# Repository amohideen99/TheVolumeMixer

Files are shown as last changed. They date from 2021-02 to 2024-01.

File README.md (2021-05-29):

# The Volume Mixer
physically control the volume of your applications

### Features
- four different knobs settable to any applications
- RGB LED bar indication for volume
- 2.8 Watts/channel integrated Class D Speaker Amp
- data and power over single USB
- runs Arduino as Metro M0 Express

### Default Application Settings
```
 Knob 1 - Main Volume
 Knob 2 - Google Chrome
 Knob 3 - Discord && Spotify
 Knob 4 - CS:GO && Valorant
 ```

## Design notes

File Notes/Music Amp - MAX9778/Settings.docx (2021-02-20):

MAX9778 pin settings

Gain for amps: set to 2 for gain a and then 2.5 for gain b

Aux jack should be 2.2 volts peak to peak max so gain of 1->2 should keep us within 5v range

Gain is Rf/Rin

Follow typical application 2 for bast boosting and cap values keep this

Gain for typical application is 1 for a and over 2 for b keep this

Follow typical applications for most

Set INL2 and INR2 to be grounded through 15k resistor and cap

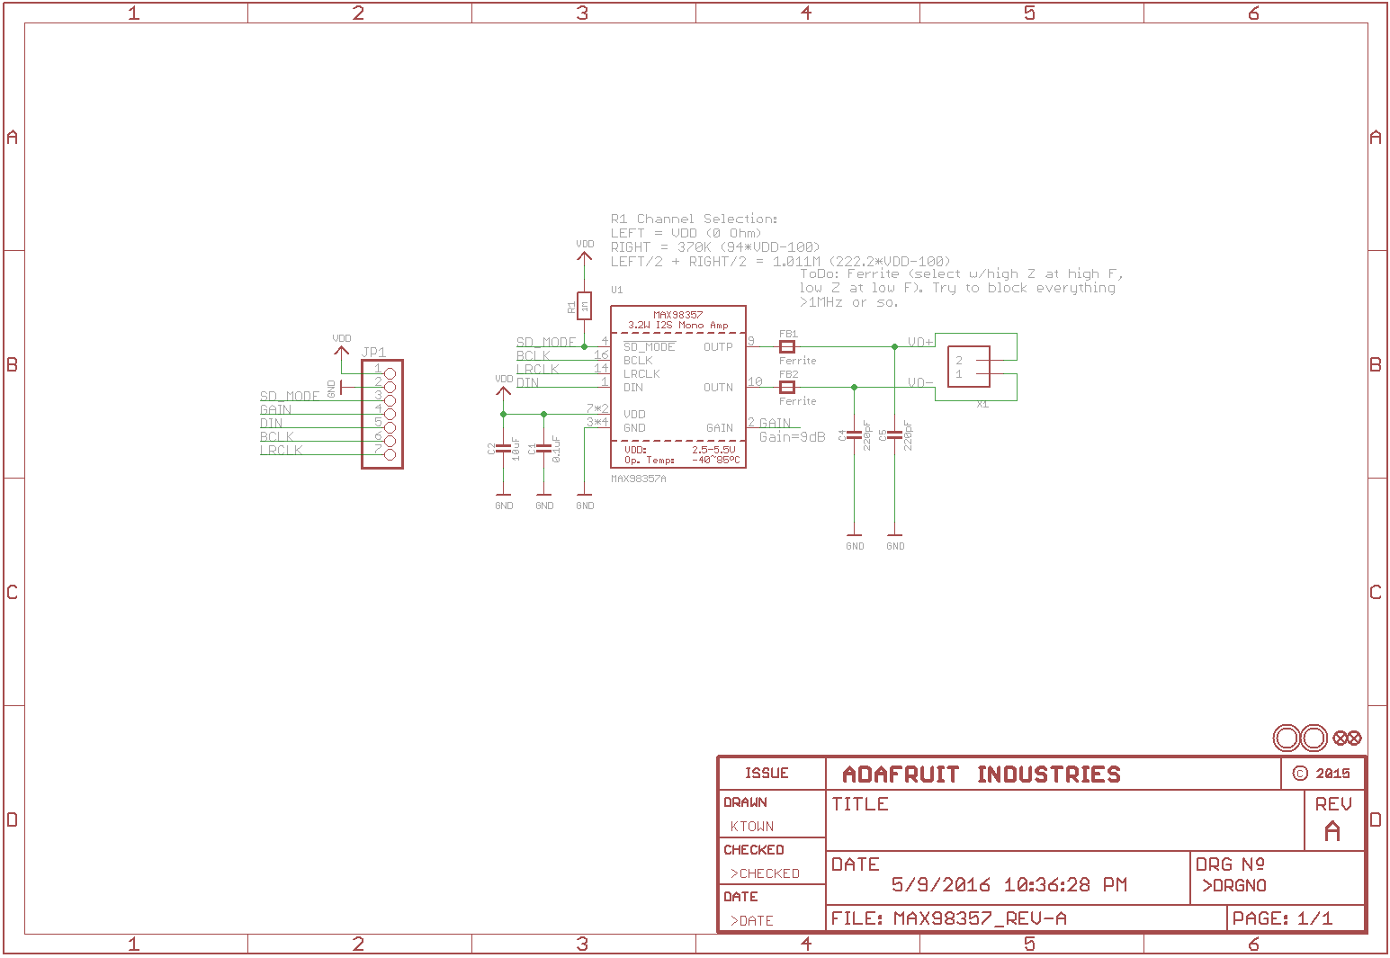
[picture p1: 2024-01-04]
Component Docs/Audio Amp - MAX98357/Adafruit Schematic.png

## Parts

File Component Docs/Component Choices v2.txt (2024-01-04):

MCU

Necessities: 4 ADC at least, I2S, Arduino Compatibility

  - **ESP32**
    | will be flashing as TinyPICO for Arduino (https://www.adafruit.com/product/4335#technical-details)
        needs PICO-D4 MCU

    | will be using online BluetoothA2DPSink for music (https://www.pschatzmann.ch/home/2020/03/27/1255/)
        need GPIOs 26, 25, 22 for I2S
    - 13 ADC
    - 2 I2S Audio
    - No Integrated USB (need UART to USB converter)
    - Bluetooth API for A2DP

  - NRF52832
    - enough GPIO
    - Bluetooth
    - Wifi (could be interesting feature)
    - can't find Bluetooth API

	- SAMD21
    - no Bluetooth features
    - enough ADC's
    - enough GPIOs

Audio Amp

	- *MAX98357*
		- arduino compatible
		- 16/24/32 bit DAC available
		- Single Channel or Mono

	- LM49450
		- 24 bit DAC
		- Stereo
    - 2.5 W per Channel
    - Digital Volume Control
    - I2C Interface

  - SSM2518
    - 2W x 2 Channel (Stereo)
    - I2C Configuration X

  - TLV320DAC32
     - I2C X
     - I2S

Pots
  - PTV09A-4020F-B203
    -

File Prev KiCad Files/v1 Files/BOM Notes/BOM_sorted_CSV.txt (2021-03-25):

0.1uF,C1 C6 C8 C9 C10 C14 C15 C16,1276-6985-1-ND,,8,24
1uF,C2 C3 C7 C11 C12 C13 C17 C20 C21,1276-1943-1-ND,,9,27
9pF,C4 C5,1276-2142-1-ND,,2,6
0.047uF,C18 C19,1276-1063-1-ND,,2,6
LED_RGBA,D1 D2 D3 D4 D5 D6,CLV1A-FKB-CK1VW1DE1BB7C3C3CT-ND,,6,18
LED,D7,754-2165-1-ND,,1,3
Conn_01x01_Male,J1 J2 J4 J5 J6 J7 J9 J10,,,8,24
Conn_01x05,J3,,,1,3
SJ1-3544,J8,CP1-3544-ND,1.01,1,3
MountingHole,MH1 MH2 MH3,,,3,9
10k,R1 R3,541-10KAQCT-ND,,2,6
3.3k,R2,541-CRCW06033K30JNEBCT-ND,,1,3
2.2k,R4,541-2.2KGCT-ND,,1,3
100k,R5,541-CRCW0603100KJNEBCT-ND,,1,3
100.0,R6 R7,541-CRCW0603100RFKEBCT-ND,,2,6
R_POT_US,RV1 RV2 RV3 RV4,PTV09A-4020F-B203-ND,,4,12
SW_Push,SW1,SW415-ND,,1,3
TLC5947RHB,U1,296-48690-1-ND,,1,3
ATSAMD21G18A-A,U2,ATSAMD21G18A-AUTCT-ND,,1,3
AP2127K-3.3,U3,AP2127K-3.3TRG1DICT-ND,,1,3
TPA2017,U4,296-24395-1-ND,,1,3
32.768kHz,Y1,2195-CM8V-T1A-32.768KHZ-9PF-20PPM-TA-QCCT-ND,,1,3

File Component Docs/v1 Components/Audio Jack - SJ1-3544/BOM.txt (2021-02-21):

3DX_CUI_DEVICES_Supplier: CUI Devices
3DX_CUI_DEVICES_Description: 3.5 mm Right-Angle Stereo Jack, 4 Pin PCB Mount, Threaded w/ Nut
3DX_CUI_DEVICES_Model Number: SJ1-3544

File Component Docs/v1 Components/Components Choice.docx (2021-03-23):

Audio Amp Possibilities

SSM4567 – Analog Devices

https://www.analog.com/en/products/ssm4567.html

- I2S

MAX98357A – MAXIM Integrated

https://www.maximintegrated.com/en/products/analog/audio/MAX98357A.html

- I2S
- Mono

SSM2315 – Analog Devices

https://www.analog.com/en/products/ssm2315.html#product-overview

- Differential
- 3W
- Mono

MAX9778 – MAXIM Integrated

https://datasheets.maximintegrated.com/en/ds/MAX9777-MAX9778.pdf

- Differential In
- I2C configurable
- Headphone/ Speaker automatic detection and switching
- 3W speaker out
- Can switch between 2 inputs
- Don’t need I2C for Max9778

LM49450 - Texas Instruments

https://www.ti.com/product/LM49450

- Headphone detection
- Class D
- Stereo 2.5W per channel
- I2C configurable
- 32 step volume control

TPA2017D2 – TI

- Class D
- 2.8W per channel w/ 4 Ohm Load @ 5V
- WFN Package
- Smart Gain (automatically determined to avoid clipping and for max amplification)
- 2 pins for setting smart gain configuration
- 1 for shutdown

MCU - ATSAMD21G18

- Program as Feather M0

Rotary Encoder

https://www.digikey.com/en/products/detail/bourns-inc/PEC11R-4220K-S0024/6164059

- 3 GPIOS for each rotary encoder (2 for left/right and 1 for push switch)

Potentiometer - PTV09A-4020U-B103

https://www.digikey.com/en/products/detail/bourns-inc/PTV09A-4020F-B203/3781126

- Single analog read input per potentiometer
- Tie between 3.3V and Ground

RGB LED

https://www.digikey.com/en/products/detail/everlight-electronics-co-ltd/EAST1616RGBB2/8510360

- Common Anode

LED Driver - TLC5947

https://www.ti.com/lit/ds/symlink/tlc5947.pdf?ts=1613292426730&ref_url=https%253A%252F%252Fwww.google.com%252F

- Adafruit libraries
- 24-channel so 8 RGB LEDs
- Constant Current sink
- IRef to set Current (2.5k sets to 20 mA)

LDO - AP212K-3.3

https://www.diodes.com/assets/Datasheets/AP2112.pdf

- 3.3V out
- 300 mA max

Power Options

- Amp works off of 5V so no need (power off 5V)
- SAMD21 has to work off of 3.3V
- TLC5940 can work off of 3V to 5V (power off 5V)
- Rotary encoder should work with 3.3V
- 3.3V LDO for MCU

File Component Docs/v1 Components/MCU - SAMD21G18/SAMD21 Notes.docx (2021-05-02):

Using as a Metro M0, so restrictions

- Only get the GPIO’s used on the Metro
- Analog Inputs can be used as Digital I/O on Metro
- Want to keep as much as same for debug purposes
- CAN use internal pull ups & should be available for pull downs
- Can source 7 mA

Design Points

- USB Data+ at PA25 and USB Data- at PA24
- 1 uF Cap at VddCore
- 0.1 uF for VDDIO
- 1 uF and 0.1 uF for VDDANA
- Reset should go to pushbutton w/ 0.1 uF cap and pull-up

Pinouts

A3 is Volume 1

A4 is Volume 2

A10 (Digital 8) will be Volume knob 3

A11 (Digital 9) will be Volume knob 4

Programming Notes

- Had issues with the crystal
- Managed to run crystalless
  - (not sure if necessary) add #define CRYSTALLESS 1 to the bootloader configuration file in uf2 bootloader
  - Rebuild and flash bootloader as necessary
    - Might not be necessary because bootloader should run cyrstalless anyway
  - Add “-DCRYSTALLESS” to the build flags for metro m0 in the boards.txt file, which is at C:\Users\Ahkeel Mohideen\AppData\Local\Arduino15\packages\adafruit\hardware\samd\1.6.6
    - This tells compiler to compile sketch as crystalless otherwise it will hang as it waits for crystal

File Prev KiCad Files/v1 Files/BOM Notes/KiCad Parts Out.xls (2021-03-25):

C1 | 0.1uF | Capacitor_SMD:C_0603_1608Metric_Pad1.05x0.95mm_HandSolder | ~ | 1276-6985-1-ND |  |  | 1
C2 | 1uF | Capacitor_SMD:C_0603_1608Metric_Pad1.05x0.95mm_HandSolder | ~ | 1276-1943-1-ND |  |  | 1
C3 | 1uF | Capacitor_SMD:C_0603_1608Metric_Pad1.05x0.95mm_HandSolder | ~ | 1276-1943-1-ND |  |  | 1
C4 | 9pF | Capacitor_SMD:C_0603_1608Metric_Pad1.05x0.95mm_HandSolder | ~ | 1276-2142-1-ND |  |  | 1
C5 | 9pF | Capacitor_SMD:C_0603_1608Metric_Pad1.05x0.95mm_HandSolder | ~ | 1276-2142-1-ND |  |  | 1
C6 | 0.1uF | Capacitor_SMD:C_0603_1608Metric_Pad1.05x0.95mm_HandSolder | ~ | 1276-6985-1-ND |  |  | 1
C7 | 1uF | Capacitor_SMD:C_0603_1608Metric_Pad1.05x0.95mm_HandSolder | ~ | 1276-1943-1-ND |  |  | 1
C8 | 0.1uF | Capacitor_SMD:C_0603_1608Metric_Pad1.05x0.95mm_HandSolder | ~ | 1276-6985-1-ND |  |  | 1
C9 | 0.1uF | Capacitor_SMD:C_0603_1608Metric_Pad1.05x0.95mm_HandSolder | ~ | 1276-6985-1-ND |  |  | 1
C10 | 0.1uF | Capacitor_SMD:C_0603_1608Metric_Pad1.05x0.95mm_HandSolder | ~ | 1276-6985-1-ND |  |  | 1
C11 | 1uF | Capacitor_SMD:C_0603_1608Metric_Pad1.05x0.95mm_HandSolder | ~ | 1276-1943-1-ND |  |  | 1
C12 | 1uF | Capacitor_SMD:C_0603_1608Metric_Pad1.05x0.95mm_HandSolder | ~ | 1276-1943-1-ND |  |  | 1
C13 | 1uF | Capacitor_SMD:C_0603_1608Metric_Pad1.05x0.95mm_HandSolder | ~ | 1276-1943-1-ND |  |  | 1
C14 | 0.1uF | Capacitor_SMD:C_0603_1608Metric_Pad1.05x0.95mm_HandSolder | ~ | 1276-6985-1-ND |  |  | 1
C15 | 0.1uF | Capacitor_SMD:C_0603_1608Metric_Pad1.05x0.95mm_HandSolder | ~ | 1276-6985-1-ND |  |  | 1
C16 | 0.1uF | Capacitor_SMD:C_0603_1608Metric_Pad1.05x0.95mm_HandSolder | ~ | 1276-6985-1-ND |  |  | 1
C17 | 1uF | Capacitor_SMD:C_0603_1608Metric_Pad1.05x0.95mm_HandSolder | ~ | 1276-1943-1-ND |  |  | 1
C18 | 0.047uF | Capacitor_SMD:C_0603_1608Metric_Pad1.05x0.95mm_HandSolder | ~ | 1276-1063-1-ND |  |  | 1
C19 | 0.047uF | Capacitor_SMD:C_0603_1608Metric_Pad1.05x0.95mm_HandSolder | ~ | 1276-1063-1-ND |  |  | 1
C20 | 1uF | Capacitor_SMD:C_0603_1608Metric_Pad1.05x0.95mm_HandSolder | ~ | 1276-1943-1-ND |  |  | 1
C21 | 1uF | Capacitor_SMD:C_0603_1608Metric_Pad1.05x0.95mm_HandSolder | ~ | 1276-1943-1-ND |  |  | 1
D1 | LED_RGBA | LED_SMD:LED_Cree-PLCC4_3.2x2.8mm_CCW |  | CLV1A-FKB-CK1VW1DE1BB7C3C3CT-ND |  |  | 1
D2 | LED_RGBA | LED_SMD:LED_Cree-PLCC4_3.2x2.8mm_CCW |  | CLV1A-FKB-CK1VW1DE1BB7C3C3CT-ND |  |  | 1
D3 | LED_RGBA | LED_SMD:LED_Cree-PLCC4_3.2x2.8mm_CCW |  | CLV1A-FKB-CK1VW1DE1BB7C3C3CT-ND |  |  | 1
D4 | LED_RGBA | LED_SMD:LED_Cree-PLCC4_3.2x2.8mm_CCW |  | CLV1A-FKB-CK1VW1DE1BB7C3C3CT-ND |  |  | 1
D5 | LED_RGBA | LED_SMD:LED_Cree-PLCC4_3.2x2.8mm_CCW |  | CLV1A-FKB-CK1VW1DE1BB7C3C3CT-ND |  |  | 1
D6 | LED_RGBA | LED_SMD:LED_Cree-PLCC4_3.2x2.8mm_CCW |  | CLV1A-FKB-CK1VW1DE1BB7C3C3CT-ND |  |  | 1
D7 | LED | LED_SMD:LED_0603_1608Metric_Pad1.05x0.95mm_HandSolder | ~ | 754-2165-1-ND |  |  | 1
J1 | Conn_01x01_Male | TestPoint:TestPoint_Pad_4.0x4.0mm | ~ |  |  |  | 1
J2 | Conn_01x01_Male | TestPoint:TestPoint_Pad_4.0x4.0mm | ~ |  |  |  | 1
J3 | Conn_01x05 | Connector_PinHeader_2.54mm:PinHeader_1x05_P2.54mm_Vertical | ~ |  |  |  | 1
J4 | Conn_01x01_Male | TestPoint:TestPoint_Pad_4.0x4.0mm | ~ |  |  |  | 1
J5 | Conn_01x01_Male | TestPoint:TestPoint_Pad_4.0x4.0mm | ~ |  |  |  | 1
J6 | Conn_01x01_Male | TestPoint:TestPoint_Pad_4.0x4.0mm | ~ |  |  |  | 1
J7 | Conn_01x01_Male | TestPoint:TestPoint_Pad_4.0x4.0mm | ~ |  |  |  | 1
J8 | SJ1-3544 | SJ1-3544 - Audio Jack:CUI_SJ1-3544 |  | CP1-3544-ND | 1.01 | Manufacturer recommendation | 1
J9 | Conn_01x01_Male | TestPoint:TestPoint_Pad_4.0x4.0mm | ~ |  |  |  | 1
J10 | Conn_01x01_Male | TestPoint:TestPoint_Pad_4.0x4.0mm | ~ |  |  |  | 1
MH1 | MountingHole | MountingHole:MountingHole_3.2mm_M3_DIN965_Pad | ~ |  |  |  | 1
MH2 | MountingHole | MountingHole:MountingHole_3.2mm_M3_DIN965_Pad | ~ |  |  |  | 1
MH3 | MountingHole | MountingHole:MountingHole_3.2mm_M3_DIN965_Pad | ~ |  |  |  | 1
R1 | 10k | Resistor_SMD:R_0603_1608Metric_Pad1.05x0.95mm_HandSolder | ~ | 541-10KAQCT-ND |  |  | 1
R2 | 3.3k | Resistor_SMD:R_0603_1608Metric_Pad1.05x0.95mm_HandSolder | ~ | 541-CRCW06033K30JNEBCT-ND |  |  | 1
R3 | 10k | Resistor_SMD:R_0603_1608Metric_Pad1.05x0.95mm_HandSolder | ~ | 541-10KAQCT-ND |  |  | 1
R4 | 2.2k | Resistor_SMD:R_0603_1608Metric_Pad1.05x0.95mm_HandSolder | ~ | 541-2.2KGCT-ND |  |  | 1
R5 | 100k | Resistor_SMD:R_0603_1608Metric_Pad1.05x0.95mm_HandSolder | ~ | 541-CRCW0603100KJNEBCT-ND |  |  | 1
R6 | 100 | Resistor_SMD:R_0603_1608Metric_Pad1.05x0.95mm_HandSolder | ~ | 541-CRCW0603100RFKEBCT-ND |  |  | 1
R7 | 100 | Resistor_SMD:R_0603_1608Metric_Pad1.05x0.95mm_HandSolder | ~ | 541-CRCW0603100RFKEBCT-ND |  |  | 1
RV1 | R_POT_US | Potentiometer - PTV09A-4020F-B203:Potentiometer_Bourns_PTV09A-1_Single_Vertical | ~ | PTV09A-4020F-B203-ND |  |  | 1
RV2 | R_POT_US | Potentiometer - PTV09A-4020F-B203:Potentiometer_Bourns_PTV09A-1_Single_Vertical | ~ | PTV09A-4020F-B203-ND |  |  | 1
RV3 | R_POT_US | Potentiometer - PTV09A-4020F-B203:Potentiometer_Bourns_PTV09A-1_Single_Vertical | ~ | PTV09A-4020F-B203-ND |  |  | 1
RV4 | R_POT_US | Potentiometer - PTV09A-4020F-B203:Potentiometer_Bourns_PTV09A-1_Single_Vertical | ~ | PTV09A-4020F-B203-ND |  |  | 1
SW1 | SW_Push | Button_Switch_SMD:SW_SPST_B3S-1000 |  | SW415-ND |  |  | 1
U1 | TLC5947RHB | Package_DFN_QFN:QFN-32-1EP_5x5mm_P0.5mm_EP3.45x3.45mm | http://www.ti.com/lit/ds/symlink/tlc5947.pdf | 296-48690-1-ND |  |  | 1
U2 | ATSAMD21G18A-A | Package_QFP:TQFP-48_7x7mm_P0.5mm | http://ww1.microchip.com/downloads/en/DeviceDoc/SAM_D21_DA1_Family_Data%20Sheet_DS40001882E.pdf | ATSAMD21G18A-AUTCT-ND |  |  | 1
U3 | AP2127K-3.3 | Package_TO_SOT_SMD:SOT-23-5 | https://www.diodes.com/assets/Datasheets/AP2127.pdf | AP2127K-3.3TRG1DICT-ND |  |  | 1
U4 | TPA2017 | footprints:TPA2017D2RTJR |  | 296-24395-1-ND |  |  | 1
Y1 | 32.768kHz | Crystal:Crystal_SMD_MicroCrystal_CC8V-T1A-2Pin_2.0x1.2mm_HandSoldering | ~ | 2195-CM8V-T1A-32.768KHZ-9PF-20PPM-TA-QCCT-ND |  |  | 1

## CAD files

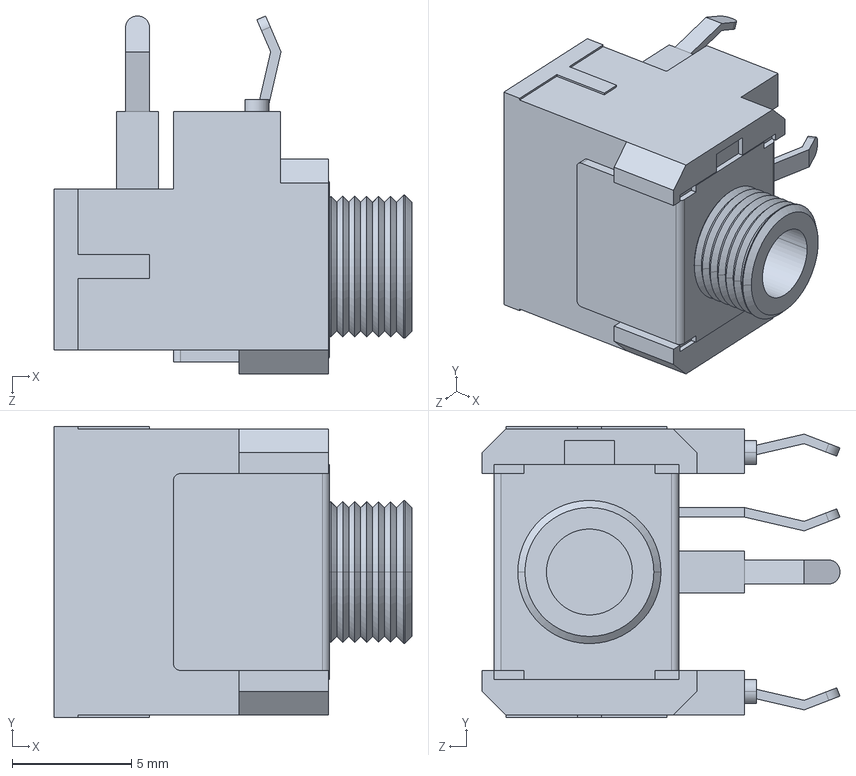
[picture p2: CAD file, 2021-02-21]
Component Docs/v1 Components/Audio Jack - SJ1-3544/CUI_DEVICES_SJ1-3544.step
15.0 x 12.2 x 15.0 mm

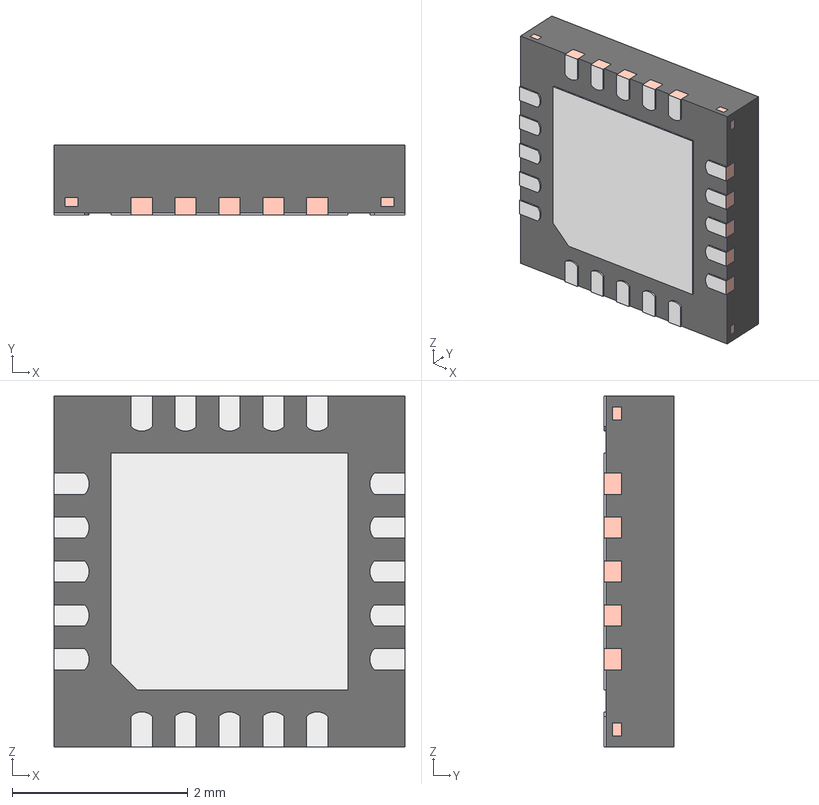
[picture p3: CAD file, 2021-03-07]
Component Docs/v1 Components/Class D Amp - TPA2017D2/STEP/RTJ0020D.stp
4.00 x 0.8 x 4.00 mm
FRAME
PIN1_AREA

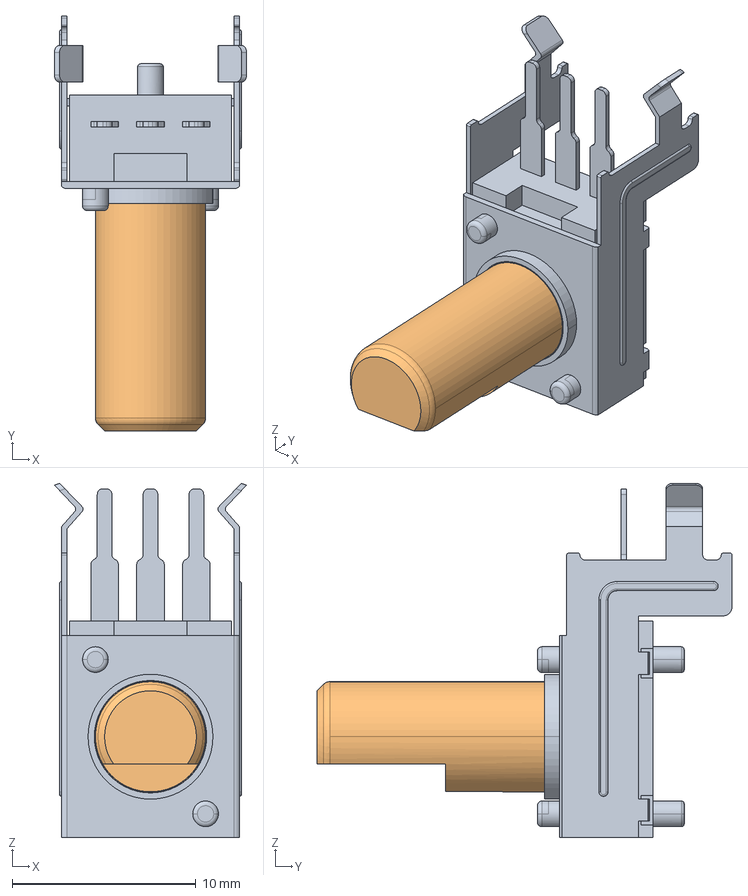
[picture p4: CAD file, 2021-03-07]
Component Docs/v1 Components/Potentiometer - PTV09A-4020F-B203/ptv09a-2x20f-xxxx.stp
10.5 x 22.6 x 19.3 mm

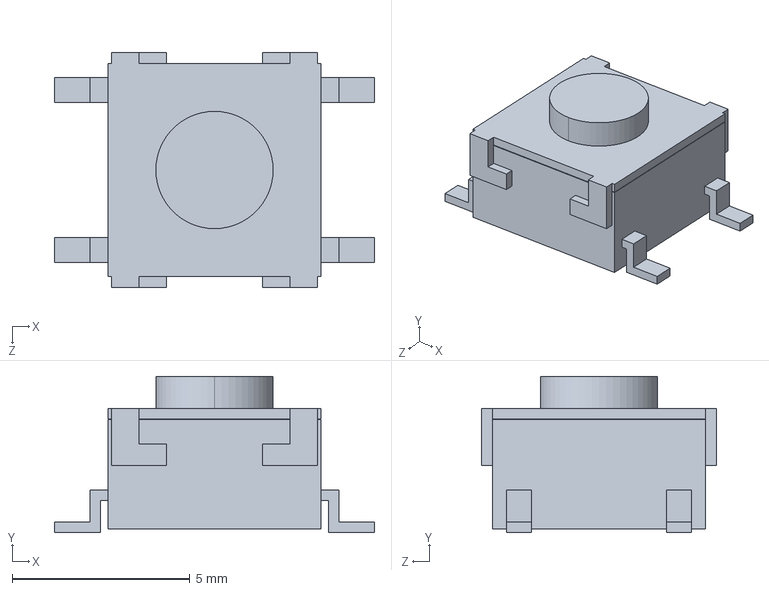
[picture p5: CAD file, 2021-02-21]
Component Docs/v1 Components/Push Button - B3S-1000/B3S_100[].step
9.00 x 4.40 x 6.60 mm

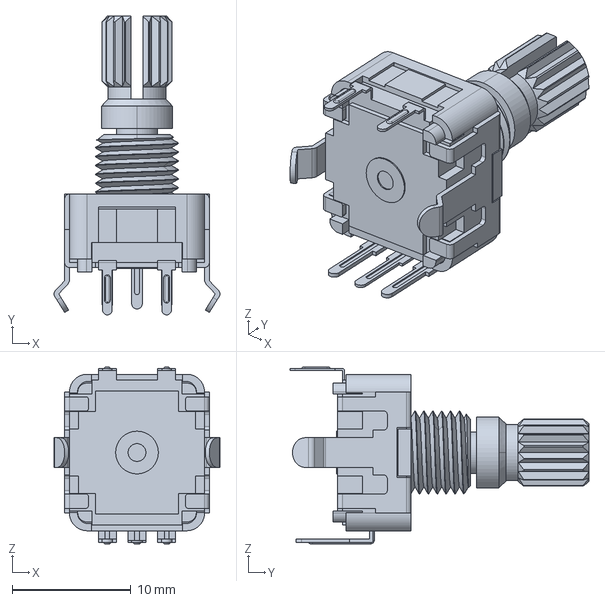
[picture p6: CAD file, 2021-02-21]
Notes/(NO USE) Rotary Encoder - PEC11R-4215K-S0012/pec11r-4x15k-sxxxx.stp
14.0 x 25.2 x 14.9 mm

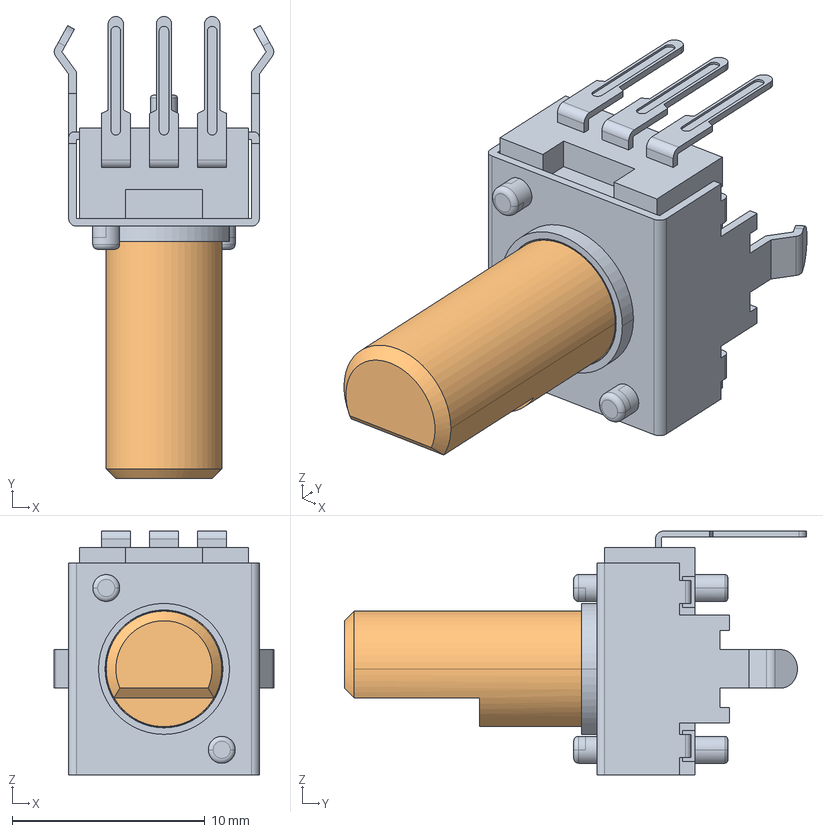
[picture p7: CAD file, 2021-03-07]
Component Docs/v1 Components/Potentiometer - PTV09A-4020F-B203/ptv09a-4x20f-xxxx.stp
11.4 x 24.0 x 12.7 mm

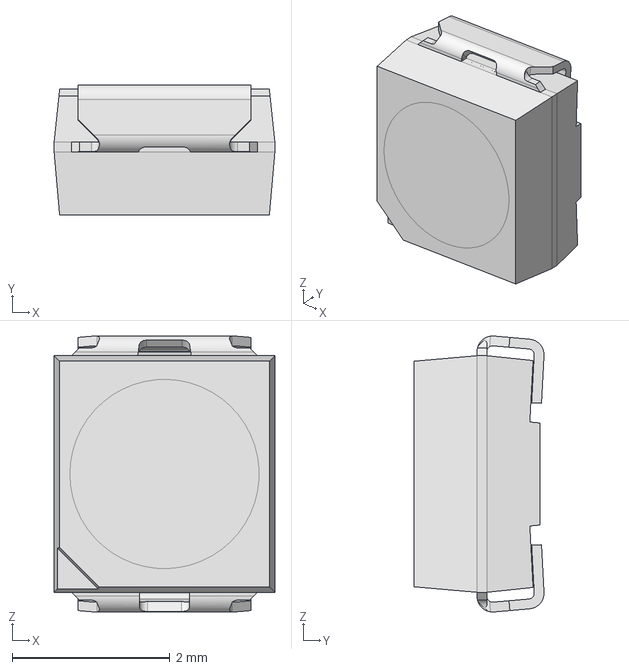
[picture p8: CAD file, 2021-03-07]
Component Docs/v1 Components/82548PLCC-2_package_3D.stp
2.80 x 1.65 x 3.50 mm

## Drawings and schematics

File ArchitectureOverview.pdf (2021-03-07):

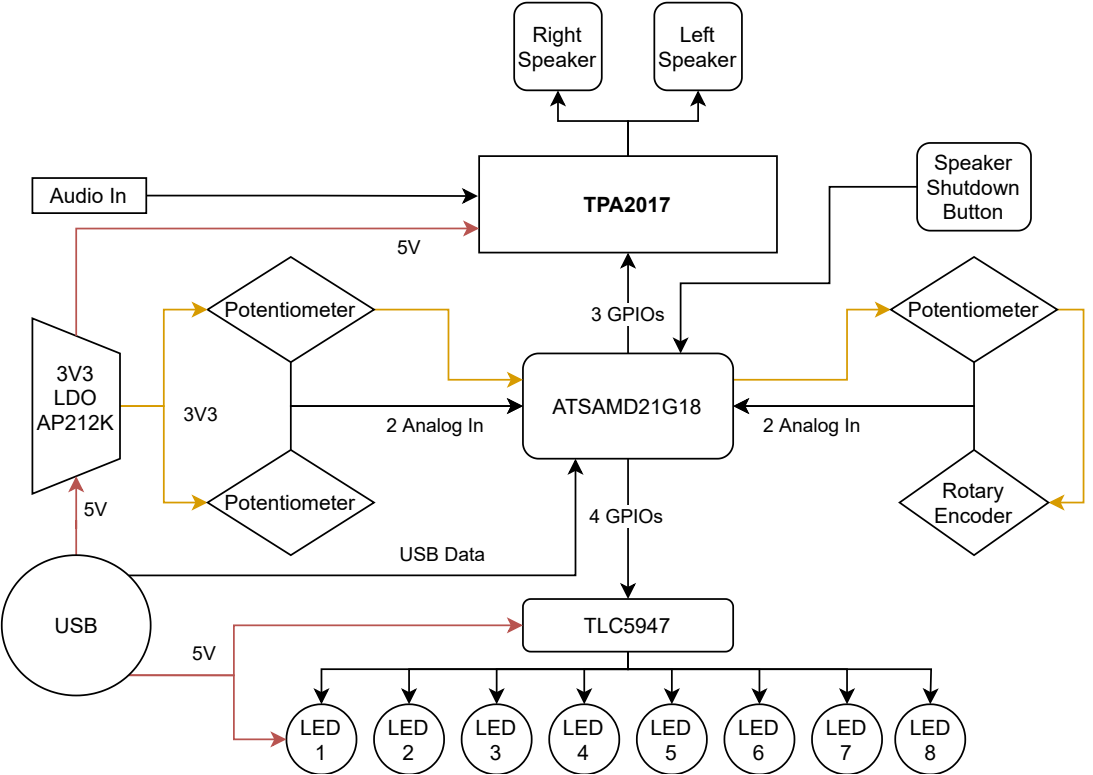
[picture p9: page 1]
Audio In; TPA2017; Right Speaker; 4 GPIOs; 3 GPIOs; ATSAMD21G18; TLC5947; LED 1; LED 2; LED 3; LED 7; LED 4; LED 5; LED 6; Potentiometer; 2 Analog In; Rotary Encoder; Left Speaker; LED 8; USB Data; USB; 3V3 LDO AP212K; Speaker Shutdown Button

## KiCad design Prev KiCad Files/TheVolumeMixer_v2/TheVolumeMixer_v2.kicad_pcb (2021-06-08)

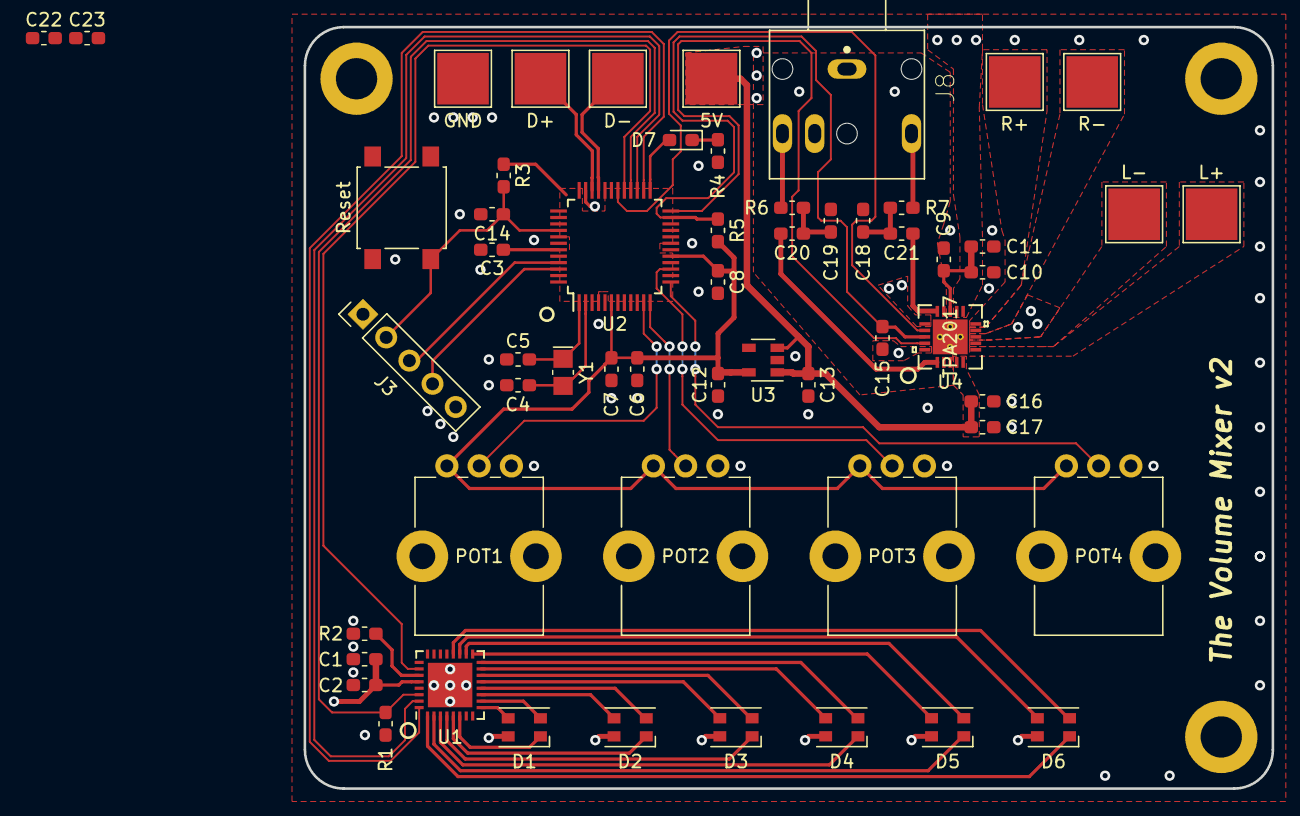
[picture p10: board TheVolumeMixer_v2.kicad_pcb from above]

Board: 2 copper layers, 75.0 x 59.0 mm, 60 parts (0 on the bottom side), 54 nets.

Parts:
5V: Conn_01x01_Male; TestPoint_Pad_4.0x4.0mm
C1, C6, C8, C9, C10, C14, C15, C16: 0.1uF; C_0603_1608Metric_Pad1.05x0.95mm_HandSolder
C2, C3, C7, C11, C12, C13, C17, C20, C21: 1uF; C_0603_1608Metric_Pad1.05x0.95mm_HandSolder
C4, C5: 9pF; C_0603_1608Metric_Pad1.05x0.95mm_HandSolder
C18, C19: 0.047uF; C_0603_1608Metric_Pad1.05x0.95mm_HandSolder
C22, C23: 100 uF; C_0603_1608Metric_Pad1.05x0.95mm_HandSolder
D1, D2, D3, D4, D5, D6: LED_RGBA; LED_Cree-PLCC4_3.2x2.8mm_CCW
D7: LED; LED_0603_1608Metric_Pad1.05x0.95mm_HandSolder
D+: Conn_01x01_Male; TestPoint_Pad_4.0x4.0mm
D-: Conn_01x01_Male; TestPoint_Pad_4.0x4.0mm
GND: Conn_01x01_Male; TestPoint_Pad_4.0x4.0mm
J3: Conn_01x05; PinHeader_1x05_P2.54mm_Vertical
J8: SJ1-3544; CUI_SJ1-3544
L+: Conn_01x01_Male; TestPoint_Pad_4.0x4.0mm
L-: Conn_01x01_Male; TestPoint_Pad_4.0x4.0mm
MH1, MH2, MH3: MountingHole; MountingHole_3.2mm_M3_DIN965_Pad
POT1, POT2, POT3, POT4: R_POT_US; Potentiometer_Bourns_PTV09A-1_Single_Vertical
R1, R3: 10k; R_0603_1608Metric_Pad1.05x0.95mm_HandSolder
R2: 3.3k; R_0603_1608Metric_Pad1.05x0.95mm_HandSolder
R4: 2.2k; R_0603_1608Metric_Pad1.05x0.95mm_HandSolder
R5: 100k; R_0603_1608Metric_Pad1.05x0.95mm_HandSolder
R6, R7: 100; R_0603_1608Metric_Pad1.05x0.95mm_HandSolder
R+: Conn_01x01_Male; TestPoint_Pad_4.0x4.0mm
R-: Conn_01x01_Male; TestPoint_Pad_4.0x4.0mm
Reset: SW_Push; SW_SPST_B3S-1000
U1: TLC5947RHB; QFN-32-1EP_5x5mm_P0.5mm_EP3.45x3.45mm
U2: ATSAMD21G18A-A; TQFP-48_7x7mm_P0.5mm
U3: AP2127K-3.3; SOT-23-5
U4: TPA2017; TPA2017D2RTJR
Y1: 32.768kHz; Crystal_SMD_MicroCrystal_CC8V-T1A-2Pin_2.0x1.2mm_HandSolder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

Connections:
+3V3: C6.1, C7.1, C8.2, C12.2, POT1.1, POT2.1, POT3.1, POT4.1, R3.1, R5.2, U2.6, U2.17, U2.36, U2.44, U3.5
+5V: 5V.1, C1.1, C2.2, C9.1, C10.1, C11.1, C13.2, C16.1, C17.1, C22.1, C23.1, D1.4, D2.4, D3.4, D4.4, D5.4, D6.4, J3.1, U1.28, U3.1, U3.3, U4.4, U4.13
/D1_B: D1.3, U1.6
/D1_G: D1.2, U1.10
/D1_R: D1.1, U1.9
/D2_B: D2.3, U1.5
/D2_G: D2.2, U1.12
/D2_LED: D7.2, U2.25
/D2_R: D2.1, U1.11
/D3_B: D3.3, U1.4
/D3_G: D3.2, U1.14
/D3_R: D3.1, U1.13
/D4_B: D4.3, U1.3
/D4_G: D4.2, U1.16
/D4_R: D4.1, U1.15
/D5_B: D5.3, U1.2
/D5_G: D5.2, U1.18
/D5_R: D5.1, U1.17
/D6_B: D6.3, U1.1
/D6_G: D6.2, U1.20
/D6_R: D6.1, U1.19
/EN: C15.1, R5.1, U2.23, U4.18
/INL+: C20.1, U4.1
/INR+: C21.1, U4.15
/LED_CLK: U1.31, U2.27
/LED_DATA: U1.32, U2.26
/LED_LATCH: U1.26, U2.29
/LED_OFF: R1.2, U1.30, U2.28
/OUTL+: L+.1, U4.5
/OUTL-: L-.1, U4.7
/OUTR+: R+.1, U4.10
/OUTR-: R-.1, U4.9
/RESET': C14.2, J3.2, R3.2, Reset.2, U2.40
/SP_GC1: U2.30, U4.17
/SP_GC2: U2.24, U4.19
/SWCLK: J3.3, U2.45
/SWDIO: J3.4, U2.46
/USB_D+: D+.1, U2.34
/USB_D-: D-.1, U2.33
/VOL1: POT1.2, U2.11
/VOL2: POT2.2, U2.12
/VOL3: POT3.2, U2.15
/VOL4: POT4.2, U2.13
GND: C1.2, C2.1, C3.2, C4.1, C5.1, C6.2, C7.2, C8.1, C9.2, C10.2, C11.2, C12.1, C13.1, C14.1, C15.2, C16.2, C17.2, C22.2, C23.2, GND.1, J3.5, POT1.3, POT2.3, POT3.3, POT4.3, R1.1, R2.1, R4.2, Reset.1, U1.29, U1.33, U2.5, U2.18, U2.35, U2.42, U3.2, U4.8, U4.16, U4.20
GNDA: C18.1, C19.1, J8.1, U4.2, U4.3, U4.14
unnamed: C3.1, U2.43
unnamed: C4.2, U2.2, Y1.2
unnamed: C5.2, U2.1, Y1.1
unnamed: C18.2, C21.2, R7.2
unnamed: C19.2, C20.2, R6.2
unnamed: D7.1, R4.1
unnamed: J8.2, R6.1
unnamed: J8.3, R7.1
unnamed: R2.2, U1.27

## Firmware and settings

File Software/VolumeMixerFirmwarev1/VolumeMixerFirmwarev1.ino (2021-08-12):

#include "Adafruit_TLC5947.h"

// pin definitions for Class D Amp (TPA2017)
#define AMP_ENABLE    2
#define AMP_CONFIG_1  7
#define AMP_CONFIG_2  5

// pin definitions for RGB LED Controller (TLC5947)
#define NUM_TLC5974   1
#define LED_DATA      13
#define LED_CLK       10
#define LED_LATCH     6
#define LED_OFF       12  

// pin definition for on-board LED
#define D7_LED        11

/********** VOLUME MIXER DEFINITIONS ************/

/* Pot 1 - Windows Master Volume
 * Pot 2 - Google Chrome
 * Pot 3 - Spotify & Discord
 * Pot 4 - Games
 */

// pin definitions for Volume Level Potentiometers
#define VOL_1         A10
#define VOL_2         A11
#define VOL_3         A7
#define VOL_4         A8

// floats for storing analog read value of potentiometers
// to detect change in volumes
float Vol_1_val = 0.0;
float Vol_2_val = 0.0;
float Vol_3_val = 0.0;
float Vol_4_val = 0.0;

// color definitions for each application [0 - 255]
#define R_VOL_1  220
#define G_VOL_1  185
#define B_VOL_1  0

#define R_VOL_2  76
#define G_VOL_2  139
#define B_VOL_2  245

#define R_VOL_3  30
#define G_VOL_3  215
#define B_VOL_3  30

#define R_VOL_4  184
#define G_VOL_4  58
#define B_VOL_4  15

// var for keeping track of LED timeout
unsigned long delayStart = 0;


// create LED controller object
Adafruit_TLC5947 LED_Controller = Adafruit_TLC5947(NUM_TLC5974, LED_CLK, LED_DATA, LED_LATCH);

/* array holding RGB LED's channel mapping
 * {D1_R, D1_G, D1_B, D2_R, D2_G, D2_B, ..., D6_B} */
int LED_pins[18] = {8, 9, 5, 10, 11, 4, 12, 13, 3, 14, 15, 2, 16, 17, 1, 18, 19, 0};

void setup() {

  // delay at beginning so we can reupload code in case of loop or Serial in use errors
  delay(1000);
  
  Serial.begin(9600);

  // begin LED_Controller & set LED's off initially
  LED_Controller.begin();
  if (LED_OFF >= 0) {
    pinMode(LED_OFF, OUTPUT);
    digitalWrite(LED_OFF, HIGH);
  }

  // set pin mode for on-board LED
  pinMode(D7_LED, OUTPUT);

  // set pin mode for Class D amp pins
  pinMode(AMP_ENABLE, OUTPUT);
  pinMode(AMP_CONFIG_1, OUTPUT);
  pinMode(AMP_CONFIG_2, OUTPUT);

  // mute amp to start and enable all features (limiter, compression, & noise gate)
  digitalWrite(AMP_ENABLE, LOW);
  digitalWrite(AMP_CONFIG_1, LOW);
  digitalWrite(AMP_CONFIG_2, LOW);

  // set volume potentiometer pins to inputs
  pinMode(VOL_1, INPUT);
  pinMode(VOL_2, INPUT);
  pinMode(VOL_3, INPUT);
  pinMode(VOL_4, INPUT);
}

void loop() {

  // print analog read values to Serial for Deej application
  printVolumeValues();

  /* if you detect change on pots, turn on LED light bar
   * and begin timer for LED timeout  */
  switch (detectAnalogChange()) {
    case 1:
      setLEDs(analogRead(VOL_1), R_VOL_1, G_VOL_1, B_VOL_1);
      delayStart = millis();
      break;
    case 2:
      setLEDs(analogRead(VOL_2), R_VOL_2, G_VOL_2, B_VOL_2);
      delayStart = millis();
      break;
    case 3:
      setLEDs(analogRead(VOL_3), R_VOL_3, G_VOL_3, B_VOL_3);
      delayStart = millis();
      break;
    case 4:
      setLEDs(analogRead(VOL_4), R_VOL_4, G_VOL_4, B_VOL_4);
      delayStart = millis();
      break;
    default:
      break;
  }

  // if LEDs have been on 2 sec, turn them off
  if (millis() - delayStart > 2000) {
    digitalWrite(LED_OFF, HIGH);
  }

  // delay for 0.1 sec before checking again
  delay(100);
}

/* if the read analog value has changed by more than 5 (ie 0.5%)
 * then return the number of the pot that has changed for proper LED control
 * & update the read value so we know if it has changed again for next time
 */
int detectAnalogChange() {

  if (abs(analogRead(VOL_1) - Vol_1_val) >= 5) {
    Vol_1_val = analogRead(VOL_1);
    return 1;
  } else if (abs(analogRead(VOL_2) - Vol_2_val) >= 5) {
    Vol_2_val = analogRead(VOL_2);
    return 2;
  } else if (abs(analogRead(VOL_3) - Vol_3_val) >= 5) {
    Vol_3_val = analogRead(VOL_3);
    return 3;
  } else if (abs(analogRead(VOL_4) - Vol_4_val) >= 5) {
    Vol_4_val = analogRead(VOL_4);
    return 4;
  }
  return 0;
}

/* sets the LEDs brightness proportionally to the pot's current
 * reading, provided the proper RGB colors (0 - 255)
 * saturates the brightness level at the defined MAX_PWM (0 - 4095)
 * 
 * using analog_read value, it sets a scalar between 0 and 6 (0 for
 * no LEDs on & 6 for all on at max level. Then, for each LED it sets,
 * it subtracts one from the scalar, so that an LED brightens to full as
 * the volume is turned up and then the next LED begins brightening, and so on.
 */
void setLEDs(float analog_read, int R_val, int G_val, int B_val) {

  // define max brightness [0 - 4095]
  #define MAX_PWM 200.0

  // scalar value calculated for LED light bar effect
  float scalar = (float) analog_read * 5.99 / 1023.0;

  // convert RGB values to PWM [0 - 255] --> [0 - MAX_PWM]
  R_val = (float) R_val * MAX_PWM / 255.0;
  G_val = (float) G_val * MAX_PWM / 255.0;
  B_val = (float) B_val * MAX_PWM / 255.0;

  // go through array and set each LED
  for(int i = 0; i < 18; i+=3) {   
    if (scalar > 1) {
      // if the scalar is greater than 1, LED should be at full brightness
      LED_Controller.setPWM(LED_pins[i], max(0, R_val));
      LED_Controller.setPWM(LED_pins[i+1], max(0, G_val));
      LED_Controller.setPWM(LED_pins[i+2], max(0, B_val));
    } else {
      // otherwise, scale the PWM value down by our scalar value
      float R_intensity = (float) R_val * scalar;
      float G_intensity = (float) G_val * scalar;
      float B_intensity = (float) B_val * scalar;
    
      LED_Controller.setPWM(LED_pins[i], max(0, R_intensity));
      LED_Controller.setPWM(LED_pins[i+1], max(0, G_intensity));
      LED_Controller.setPWM(LED_pins[i+2], max(0, B_intensity));
    }
    scalar = (float) scalar - 1.0;
  }
  // finally write the data and turn the LEDs on
  LED_Controller.write();
  digitalWrite(LED_OFF, LOW);
}

/* create the properly formatted string for the Serial monitor
 * that Deej is designed to read. More info on Deej Github page.
 * format should be "Level 1 | Level 2 | Level 3 | Level 4 ..."
 * each level should be a value [0 - 1024] (the raw analog read value)
 */
void printVolumeValues() {
  // create empty string  
  String builtString = String("");

  // build the string mulitply by 0.75 to cap max volume at 75%
  builtString += String( (int) ((float) analogRead(VOL_1) / 1024 * analogRead(VOL_1) * 0.75));
  builtString += String("|");
  builtString += String( (int) ((float) analogRead(VOL_2) / 1024 * analogRead(VOL_2) * 0.75));
  builtString += String("|");
  builtString += String( (int) ((float) analogRead(VOL_3) / 1024 * analogRead(VOL_3) * 0.75));
  builtString += String("|");
  builtString += String( (int) ((float) analogRead(VOL_4) / 1024 * analogRead(VOL_4) * 0.75));
  
  // print it to Serial Monitor
  Serial.println(builtString);
}

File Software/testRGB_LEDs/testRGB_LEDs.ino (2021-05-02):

#include "Adafruit_TLC5947.h"

// How many boards do you have chained?
#define NUM_TLC5974 1

#define LED_DATA   13
#define LED_CLK   10
#define LED_LATCH   6
#define LED_OFF  -1  // set to -1 to not use the enable pin (its optional)
#define D7_LED 11

Adafruit_TLC5947 tlc = Adafruit_TLC5947(NUM_TLC5974, LED_CLK, LED_DATA, LED_LATCH);

// array holding RGB LED's pin mapping
// {D1_R, D1_G, D1_B, D2_R, D2_G, D2_B, ..., D6_B}
int LED_pins[18] = {5, 9, 8, 4, 11, 10, 3, 13, 12, 2, 15, 14, 1, 17, 16, 0, 19, 18};

int R_value = 127 * 4095 / 255;
int G_value = 0 * 4095 / 255;
int B_value = 255 * 4095 / 255;

double SCALAR = 4.15;

void setup() {
  Serial.begin(9600);
  
  Serial.println("TLC5974 test");
  tlc.begin();
  if (LED_OFF >= 0) {
    pinMode(LED_OFF, OUTPUT);
    digitalWrite(LED_OFF, LOW);
  }
  //setWhite();
  pinMode(D7_LED, OUTPUT);
}

void loop() {
  SCALAR = Serial.parseFloat();
  Serial.println(SCALAR);
  digitalWrite(D7_LED, LOW);
  setWhite();
  delay(1000);
  digitalWrite(D7_LED, HIGH);
  delay(1000);
}

void setWhite() {
  
/*  int R_scaled = R_value * scalar;
  int G_scaled = G_value * scalar;
  int B_scaled = B_value * scalar;*/

  double scalar = SCALAR;
  
  for(int i = 0; i < 18; i+=3) {
    int R_val = R_value*scalar;
    int G_val = G_value*scalar;
    int B_val = B_value*scalar;
    
    tlc.setPWM(LED_pins[i],  max(0, min(1000, R_val)));
    tlc.setPWM(LED_pins[i+1], max(0, min(1000, G_val)));
    tlc.setPWM(LED_pins[i+2], max(0, min(1000, B_val)));
    scalar--;
    
  }
  tlc.write();
}

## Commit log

2021-02-13 editted Component selection and created KiCad project files
    [TheVolumeMixer.kicad_pcb, TheVolumeMixer.sch]
2021-02-14 updated Architecture, Finalized components, started on schematic
    [TheVolumeMixer.sch]
2021-02-14 finished schematic w/o Audio Amp. designated unusable pins due to Feather M0
    [TheVolumeMixer.sch]
2021-02-14 added NC's for pins not usuable as Feather M0
    [TheVolumeMixer.sch]
2021-02-14 added USB data and 5V to Architecture Overview
2021-02-20 completed schematic v1, created settings doc for MAX9778
    [TheVolumeMixer.sch]
2021-02-20 schematic finished! checked once.
    [TheVolumeMixer.sch]
2021-02-21 updated libraries, finalized schematic symbols, added footprints
    [TheVolumeMixer.sch]
2021-02-21 removed unnecessary parts, started on PCB layout
    [TheVolumeMixer.sch, _saved_TheVolumeMixer.sch]
2021-02-21 worked on PCB layout
    [TheVolumeMixer.kicad_pcb, TheVolumeMixer.sch, _saved_TheVolumeMixer.sch]
2021-02-21 finalized PCB layout. added 3D shapes for most components
    [B3S_100[].step, CUI_DEVICES_SJ1-3544.step, TheVolumeMixer.kicad_pcb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]
2021-03-03 changed pinout for MCU, replaced rotary encoders with potentiometers
    [B3S_100[].step, CUI_DEVICES_SJ1-3544.step, TheVolumeMixer.sch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]
2021-03-03 editted MCU pinout and capacitors
    [TheVolumeMixer.sch]
2021-03-07 changed architecture and speaker amp choice
    [pec11r-4x15k-sxxxx.stp]
2021-03-07 added TPA2017 to circuit diagram and made necessary net changes
    [TheVolumeMixer.sch]
2021-03-07 PCB traces MCU, Volume Knobs, and Class D Amp routed
    [RTJ0020D.stp, TheVolumeMixer.kicad_pcb, TheVolumeMixer.sch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]
2021-03-07 rev 1 PCB complete -- not finished
    [TheVolumeMixer.kicad_pcb, TheVolumeMixer.sch]
2021-03-07 created 3D preview
    [82548PLCC-2_package_3D.stp, TheVolumeMixer.kicad_pcb]
2021-03-09 fixed power traces for music amp, added all 3D models
    [TheVolumeMixer.kicad_pcb]
2021-03-23 updated Notes and made PCB updates
    [Pin30MCUChange.kicad_pcb, TheVolumeMixer.kicad_pcb, TheVolumeMixer.sch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]
2021-03-23 PCB finished, Gerbers exported
    [TheVolumeMixerV2-B.Cu.gbr, TheVolumeMixerV2-B.Mask.gbr, TheVolumeMixerV2-B.SilkS.gbr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]
2021-03-23 made changes to SilkScreen. Regened Gerbers
    [TheVolumeMixerV2-B.Cu.gbr, TheVolumeMixerV2-B.Mask.gbr, TheVolumeMixerV2-B.SilkS.gbr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]
2021-03-25 PCB finished, BOM created, file system reorganized
    [KiCad Parts Out.xls, Pin30MCUChange.kicad_pcb, TheVolumeMixer.kicad_pcb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]
2021-05-02 Software Working Great! Enjoy!
    [TheVolumeMixer.sch]
2021-05-29 README and file system update
    [82548PLCC-2_package_3D.stp, B3S_100[].step, CUI_DEVICES_SJ1-3544.step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]
2021-05-29 schematic reference updates
2021-06-08 added caps for pots
    [TheVolumeMixer_v2.sch]
2021-08-09 changed file system
    [82548PLCC-2_package_3D.stp, B3S_100[].step, CUI_DEVICES_SJ1-3544.step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]
2024-01-04 re-commit before starting v3
    [CUI_DEVICES_SJ1-3544.step]
2024-01-04 created fresh v3 directories
    [KiCad Parts Out.xls, TheVolumeMixer.kicad_pcb, TheVolumeMixer.sch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]

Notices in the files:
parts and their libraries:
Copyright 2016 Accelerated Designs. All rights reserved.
